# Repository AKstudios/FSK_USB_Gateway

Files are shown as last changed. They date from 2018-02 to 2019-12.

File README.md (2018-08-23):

# FSK-USB-Gateway
This is a USB gateway for the RFM69 FSK module. Incoming wireless data is sent to the host computer over serial.

<p align="center">
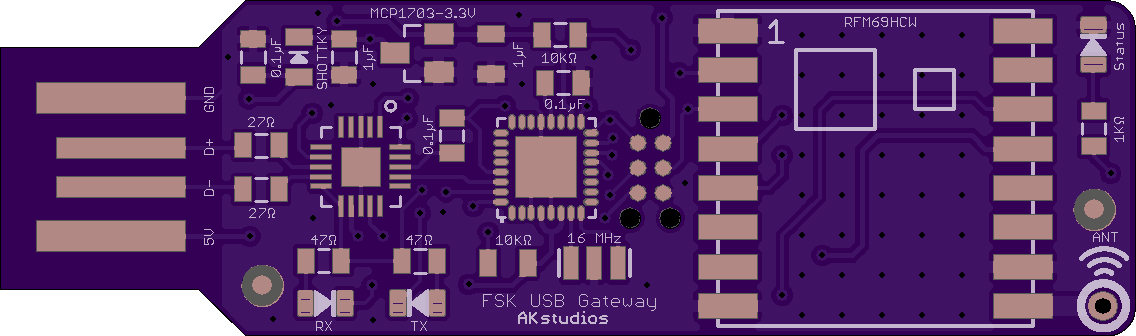
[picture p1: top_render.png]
OSH Park PCB render - front
  
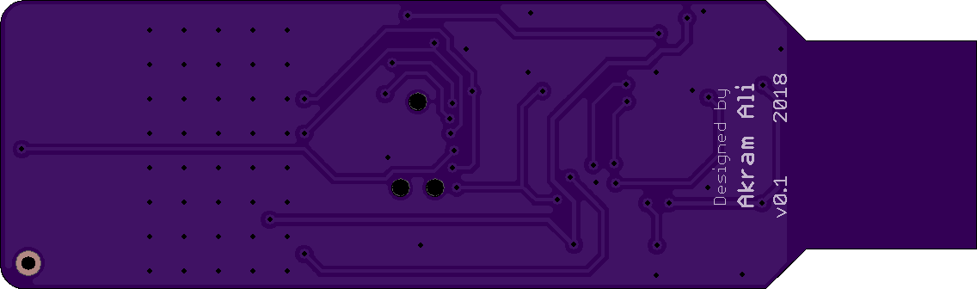
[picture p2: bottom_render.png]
OSH Park PCB render - back
  
</p>

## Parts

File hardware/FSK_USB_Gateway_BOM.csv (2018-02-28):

Designator | Manufacturer Part Number | Quantity
C1, C5, C6 | CC0805KRX7R9BB104 | 3
R1 | RC0805FR-0710KL | 1
R7 | RC0805FR-0710KL | 1
X1 | CSTCE16M0V53-R0 | 1
R2 | RC0805FR-071KL | 1
C2, C4 | CC0805ZRY5V8BB105 | 2
R3, R5 | RC0805FR-0727RL | 2
R4, R6 | RC0805FR-0747RL | 2
U2 | ATMEGA328P-MU | 1
FT231XQ-R | FT231XQ-R | 1
RX | LG R971-KN-1 | 1
IC3 | MCP1703T-3302E/CB | 1
U1 | RFM69HCW | 1
TX | LG R971-KN-1 | 1
D | SD0805S040S0R5 | 1
U$2 | LG R971-KN-1 | 1

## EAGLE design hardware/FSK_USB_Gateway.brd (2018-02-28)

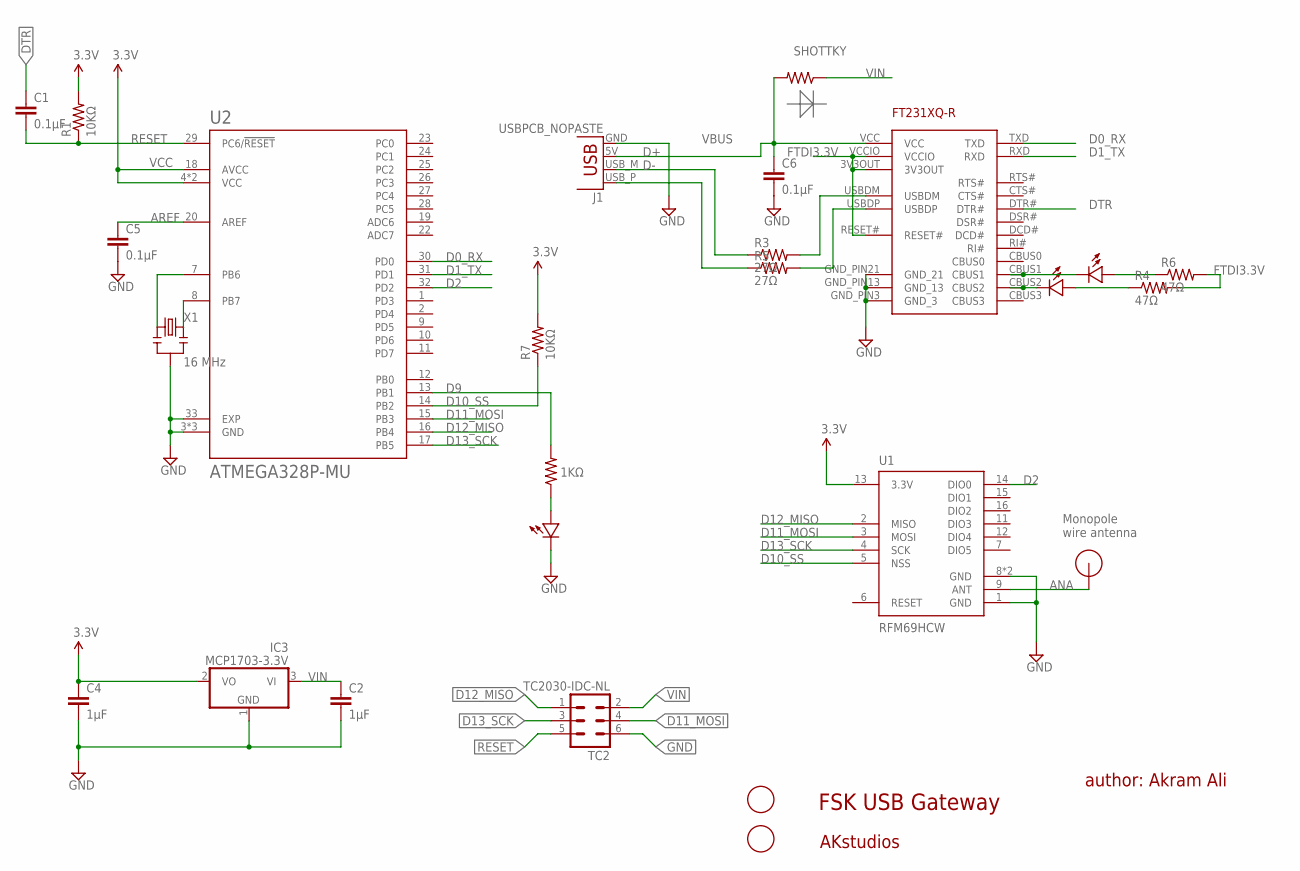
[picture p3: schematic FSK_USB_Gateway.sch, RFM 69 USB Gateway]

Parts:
C1, C5, C6: 0.1μF; 0805; MPN CC0805KRX7R9BB104
C2, C4: 1μF; 0805; MPN CC0805ZRY5V8BB105
D: SHOTTKY; 0805; MPN SD0805S040S0R5
FT231XQ-R: FT231XQ-R; FTDI_FT231XQ-R_PACKAGE; MPN FT231XQ-R
IC3: MCP1703-3.3V; SOT23; MPN MCP1703T-2502E/CB
J1: USBPCB_NOPASTE; USB-A-PCB-NOPASTE
R1, R7: 10KΩ; 0805; MPN RC0805FR-0710KL
R2: 1KΩ; 0805; MPN RC0805FR-071KL
R3, R5: 27Ω; 0805; MPN RC0805FR-0727RL
R4, R6: 47Ω; 0805; MPN RC0805FR-0747RL
RX: Green; 0805-LED; MPN LG R971-KN-1
TC2: TC2030-IDC-NL
TX: Red; 0805-LED; MPN LG R971-KN-1
U1: RFM69HCW; RFM69HCW-XXXS2; MPN RFM69HW
U2: ATMEGA328P-MU; QFN50P500X500X100-33N; MPN ATmega328P-MU
U$2: Status; 0805-LED; MPN LG R971-KN-1
U$3, U$4: FIDUCIAL; FIDUCIAL_1MM
U$6: RFM12B_ANTENNA; RFM12B-ANTENNA
X1: 16 MHz; RESONATOR-SMD; MPN CSTCE16M0V53-R0

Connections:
ANA: U1.9 (ANT), U$6.P$1
AREF: C5.1, U2.20 (AREF)
D0_RX: FT231XQ-R.TXD, U2.30 (PD0)
D1_TX: FT231XQ-R.RXD, U2.31 (PD1)
D2: U1.14 (DIO0), U2.32 (PD2)
D9: R2.2, U2.13 (PB1)
D10_SS: R7.1, U1.5 (NSS), U2.14 (PB2)
D11_MOSI: TC2.4, U1.3 (MOSI), U2.15 (PB3)
D12_MISO: TC2.1, U1.2 (MISO), U2.16 (PB4)
D13_SCK: TC2.3, U1.4 (SCK), U2.17 (PB5)
D+: J1.USB_P (D+), R5.1
D-: J1.USB_M (D-), R3.1
DTR: C1.1, FT231XQ-R.DTR#
FTDI3.3V: FT231XQ-R.3V3OUT, FT231XQ-R.RESET#, FT231XQ-R.VCCIO, R4.2, R6.2
GND: C2.2, C4.2, C5.2, C6.2, FT231XQ-R.GND_PIN3 (GND_3), FT231XQ-R.GND_PIN13 (GND_13), FT231XQ-R.GND_PIN21 (GND_21), IC3.1 (GND), J1.GND, TC2.6, U1.1 (GND), U1.8 (GND), U1.10 (GND), U2.3 (GND), U2.5 (GND), U2.21 (GND), U2.33 (EXP), U$2.MINUS, X1.2
unnamed: U2.7 (PB6), X1.1
unnamed: R2.1, U$2.PLUS
unnamed: FT231XQ-R.USBDM, R3.2
unnamed: FT231XQ-R.USBDP, R5.2
unnamed: FT231XQ-R.CBUS1, RX.MINUS
unnamed: FT231XQ-R.CBUS2, TX.MINUS
unnamed: R4.1, TX.PLUS
unnamed: R6.1, RX.PLUS
unnamed: U2.8 (PB7), X1.3
RESET: C1.2, R1.1, TC2.5, U2.29 (PC6/!RESET)
VBUS: C6.1, D.2, FT231XQ-R.VCC, J1.5V (VBUS)
VCC: C4.1, IC3.2 (VO), R1.2, R7.2, U1.13 (3.3V), U2.4 (VCC), U2.6 (VCC), U2.18 (AVCC)
VIN: C2.1, D.1, IC3.3 (VI), TC2.2

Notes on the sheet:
FSK USB Gateway
author: Akram Ali
AKstudios
Monopole wire antenna

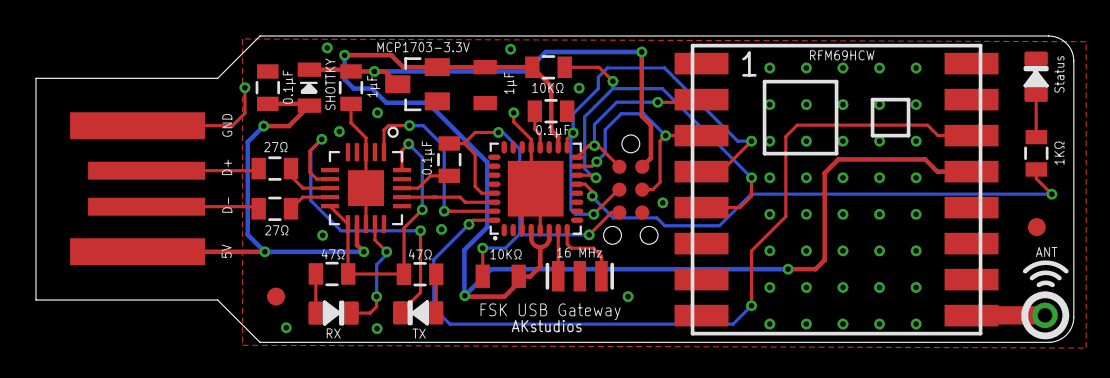
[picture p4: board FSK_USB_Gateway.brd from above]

Board: 2 copper layers, 57.7 x 17.0 mm, 26 parts (0 on the bottom side), 28 nets.

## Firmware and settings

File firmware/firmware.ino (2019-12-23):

// FSK USB Gateway firmware
// Updated on 12/22/2019

#include <RFM69.h>         //http://github.com/lowpowerlab/rfm69
//#include <SPIFlash.h>      //http://github.com/lowpowerlab/spiflash
#include <SPI.h>           

#define ENCRYPTKEY    "Tt-Mh=SQ#dn#JY3_" //has to be same 16 characters/bytes on all nodes, not more not less!
#define NODEID        1
#define NETWORKID     1
#define FREQUENCY     RF69_915MHZ //(others: RF69_433MHZ, RF69_868MHZ)
#define IS_RFM69HW    //uncomment only for RFM69HW! Leave out if you have RFM69W!
#define LED           9
#define SERIAL_BAUD   115200
//*****************************************************************************************************************************

RFM69 radio;
//SPIFlash flash(FLASH_CS, 0xEF30); //EF40 for 16mbit windbond chip
char data[100];
char dataPacket[150];
char _rssi[5];
char _i[4];

void setup()
{
  pinMode(10, OUTPUT);
  Serial.begin(SERIAL_BAUD);

  radio.initialize(FREQUENCY,NODEID,NETWORKID);
#ifdef IS_RFM69HW
  radio.setHighPower(); //uncomment only for RFM69HW!
#endif
  radio.encrypt(ENCRYPTKEY);
  //flash.initialize();
}

void loop()
{
  if (radio.receiveDone())
  {
    int rssi = radio.RSSI;
    int nodeID = radio.SENDERID;

    if (radio.DATALEN > 0)
    {
      for (byte i = 0; i < radio.DATALEN; i++)
        data[i] = (char)radio.DATA[i];
    }
    
    if (radio.ACKRequested())
    {
      radio.sendACK();

      dtostrf(nodeID, 1, 0, _i);
      dtostrf(rssi, 3, 0, _rssi);

      dataPacket[0] = 0;  // first value of dataPacket should be a 0
      strcat(dataPacket, "i:");
      strcat(dataPacket, _i);  // append node ID
      strcat(dataPacket, ",");
      strcat(dataPacket, data);  // append actual data
      strcat(dataPacket, ",r:");
      strcat(dataPacket, _rssi); // append RSSI
      
      Serial.println(dataPacket);
      delay(1);

      memset(data, 0, sizeof data);   // clear array
      memset(dataPacket, 0, sizeof dataPacket);   // clear array
      memset(_rssi, 0, sizeof _rssi);

      Blink(LED,5);
    }
  }
}

void Blink(byte PIN, int DELAY_MS)
{
  pinMode(PIN, OUTPUT);
  digitalWrite(PIN,HIGH);
  delay(DELAY_MS);
  digitalWrite(PIN,LOW);
}

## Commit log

2018-04-16 Minor firmware update
    - Removed config file
    - Added main gateway (code currently set to receive wireless data only, doesn't transmit anything yet)
    [firmware.ino]
2018-04-24 commented SPI flash code

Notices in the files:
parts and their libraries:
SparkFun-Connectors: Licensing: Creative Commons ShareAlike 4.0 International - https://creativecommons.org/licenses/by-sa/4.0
